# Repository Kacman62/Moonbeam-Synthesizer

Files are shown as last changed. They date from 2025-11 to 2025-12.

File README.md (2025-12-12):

# MoonBeam Synthesizer
A standalone DAWLESS synthesizer based on a Raspberry Pi Pico. Includes a custom circuit board and codebase with the Mozzi Audio Library

Promo Image for the Moonbeam Synth

# Features

- 25 multiplexed piano style keys
- Support for up to 5 notes at the same time
- 3 Analog sliders for volume pitch and vibrato
- OLED display and 2 rotary encoders with a custom code base
- Sound synthesis using the Mozzi audio library
- 4 different wave forms
- Custom ADSR editing
- Oscilloscope style waveform viewer
- Toggleable speaker and headphone out
- Audio effects and filters
- Preset sound fforms

# Initial Idea
After reading the guide from Hack club and others online to make a MIDI keyboard, it seemed like a great idea. After more research though I wanted a standalone synthesizer that does not need a computer and couldn't find many examples online. This seemed like it would be easy enough so I decided to do it myself

# Schematic and Board
The whole project is built around a raspberry pi pico 1 (a pico 2 should work too but untested). A 5x5 multiplexed array of key cap switches serve as the main input. 
On the Audio side, a PCM5100 I2S DAC is channeled into a LM4810 and LM4861 audio amplifiers, that go to a speaker and headphone jack.

Image showing routing of PCB

The PCB was a lot more challenging, just due to the sheer size of it. It ends up being about 350mm x 90mm. But the routing wasn't too hard and I like the look of how it turned out

# Case Design
There is an included case. Currently I have not received the board so I can not confirm if it works perfectly, but I designed it around the 3D cad of the board so it should work fine. 
Only 1 of each file needs to be printed and it is assembled using M4 hardware

Image showing CAD of the case

# Software
I initially dreaded the software but it ended up being very fun after the initial hurdles. The code is split into 2 cores, 1 for audio and 1 for the digital UI. It should work with the final assembly, all the digital has been tested, but the audio is using I2S which I can't test currently. I did use it a little bit with PWM audio and that worked fine. The waveform viewer also does show an audio signal so Im pretty confident that it will work

# UI
You navigate the UI with both rotary encoders. Double clicking either brings you into the main menu. Rotate either to select an app.
* Settings (Wrench): View current notes on each audio voice and the values of the slide potentiometers
* ADSR Editor (Envelope): Use one dial to change the level of the ADSR and the other to change the time. Changing the level of the decay, sustain and release will change the other two with it. this is intended to avoid weird audio clipping
* Wave Viewer (Wave): View the current outputted wave form. Automatically adjusts the zoom if multiple voices are playing
* Wave Changer (Square Wave): Choose from either a sin, triangle, saw, or square wave

Image showing the settings UI

# Art
All pixel art was created by me using Aseprite. The PK Industries and the Moonbeam synth logo are unregistered trademarks, not real companies and products, and have no legal binding on anything. I am not a lawyer, and this joke has gone on too long.

Image showing the pixel art for the project

# Disclaimers
If you want to know more about the design and build process check out the journal

This project is sponsored by and made in collaboration with Hack Club, go check them out

Consider this project untested. I have put my full effort into this project and fully believe that it will work, but I have not received boards yet and thus do not know if this will work first try

# Hack Club Stuff

Estimate Total Hours: 48

My Final Total: 60.31

Your Final Total: 96.73

https://blueprint.hackclub.com/projects/928 

# Update 11/11

Huge thanks to Hack Club and the Blueprint program for assisting in this project. I have now received funding for the project and will be ordering parts. Expect future updates at the start of December

# Update 11/25

Boards have been received. Still waiting on LCSC order. Small errors have been found in the board and have been fixed in the PCB files

# Update 12/1

Boards have been assembled and multiple errors have been found. The files will still be up, but assume they do not work.
Nothing shorts together, but both the button matrix is broken, as well as the I2S DAC and amplifier not working.

# Update 12/3

After reflowing the baord, the issue has been fixed. Two of the data lines into the DAC were shorted and after fixing that, it makes sound. The code still has some issues, but they are being fixed rapidly and the current board is almost done.

# Update 12/4 

This project is now shipped. I had a lot of fun working on this, and will continue to update the software, but for now the project is in a working state so expect less updates.

# Update 12/12 

Version 1 of software is now released. This features upgrades to all parts of the code base. Numerous bug fixes, rewritten audio workflow. Support for filters, effects, and presets. Improved menus and clarity. 

# Known issues

Code: 

In settings, the note played is incorrect (going to wait for boards to arrive so I can assign keys different notes) Fixed 12/12/25

Button scanning matrix is incorrect, every button plays the same 5 notes FIXED 12/3/25

In Wave changer, the picture of the sawtooth wave is reversed from what is seen in the wave viewer

In Wave Viewer, the wave slides around randomly. (The wave is still representative of what the audio out looks like, it's just hard to focus on it)

Distortion effect is unstable and clips audio most of the time. Still able to be used in code, but not recomended

Board:

Slide pot pin spacing 2.00mm instead of 2.54mm FIXED 11/25/25

Resistor footprint 7.62mm instead of 12.04mm FIXED 11/25/25

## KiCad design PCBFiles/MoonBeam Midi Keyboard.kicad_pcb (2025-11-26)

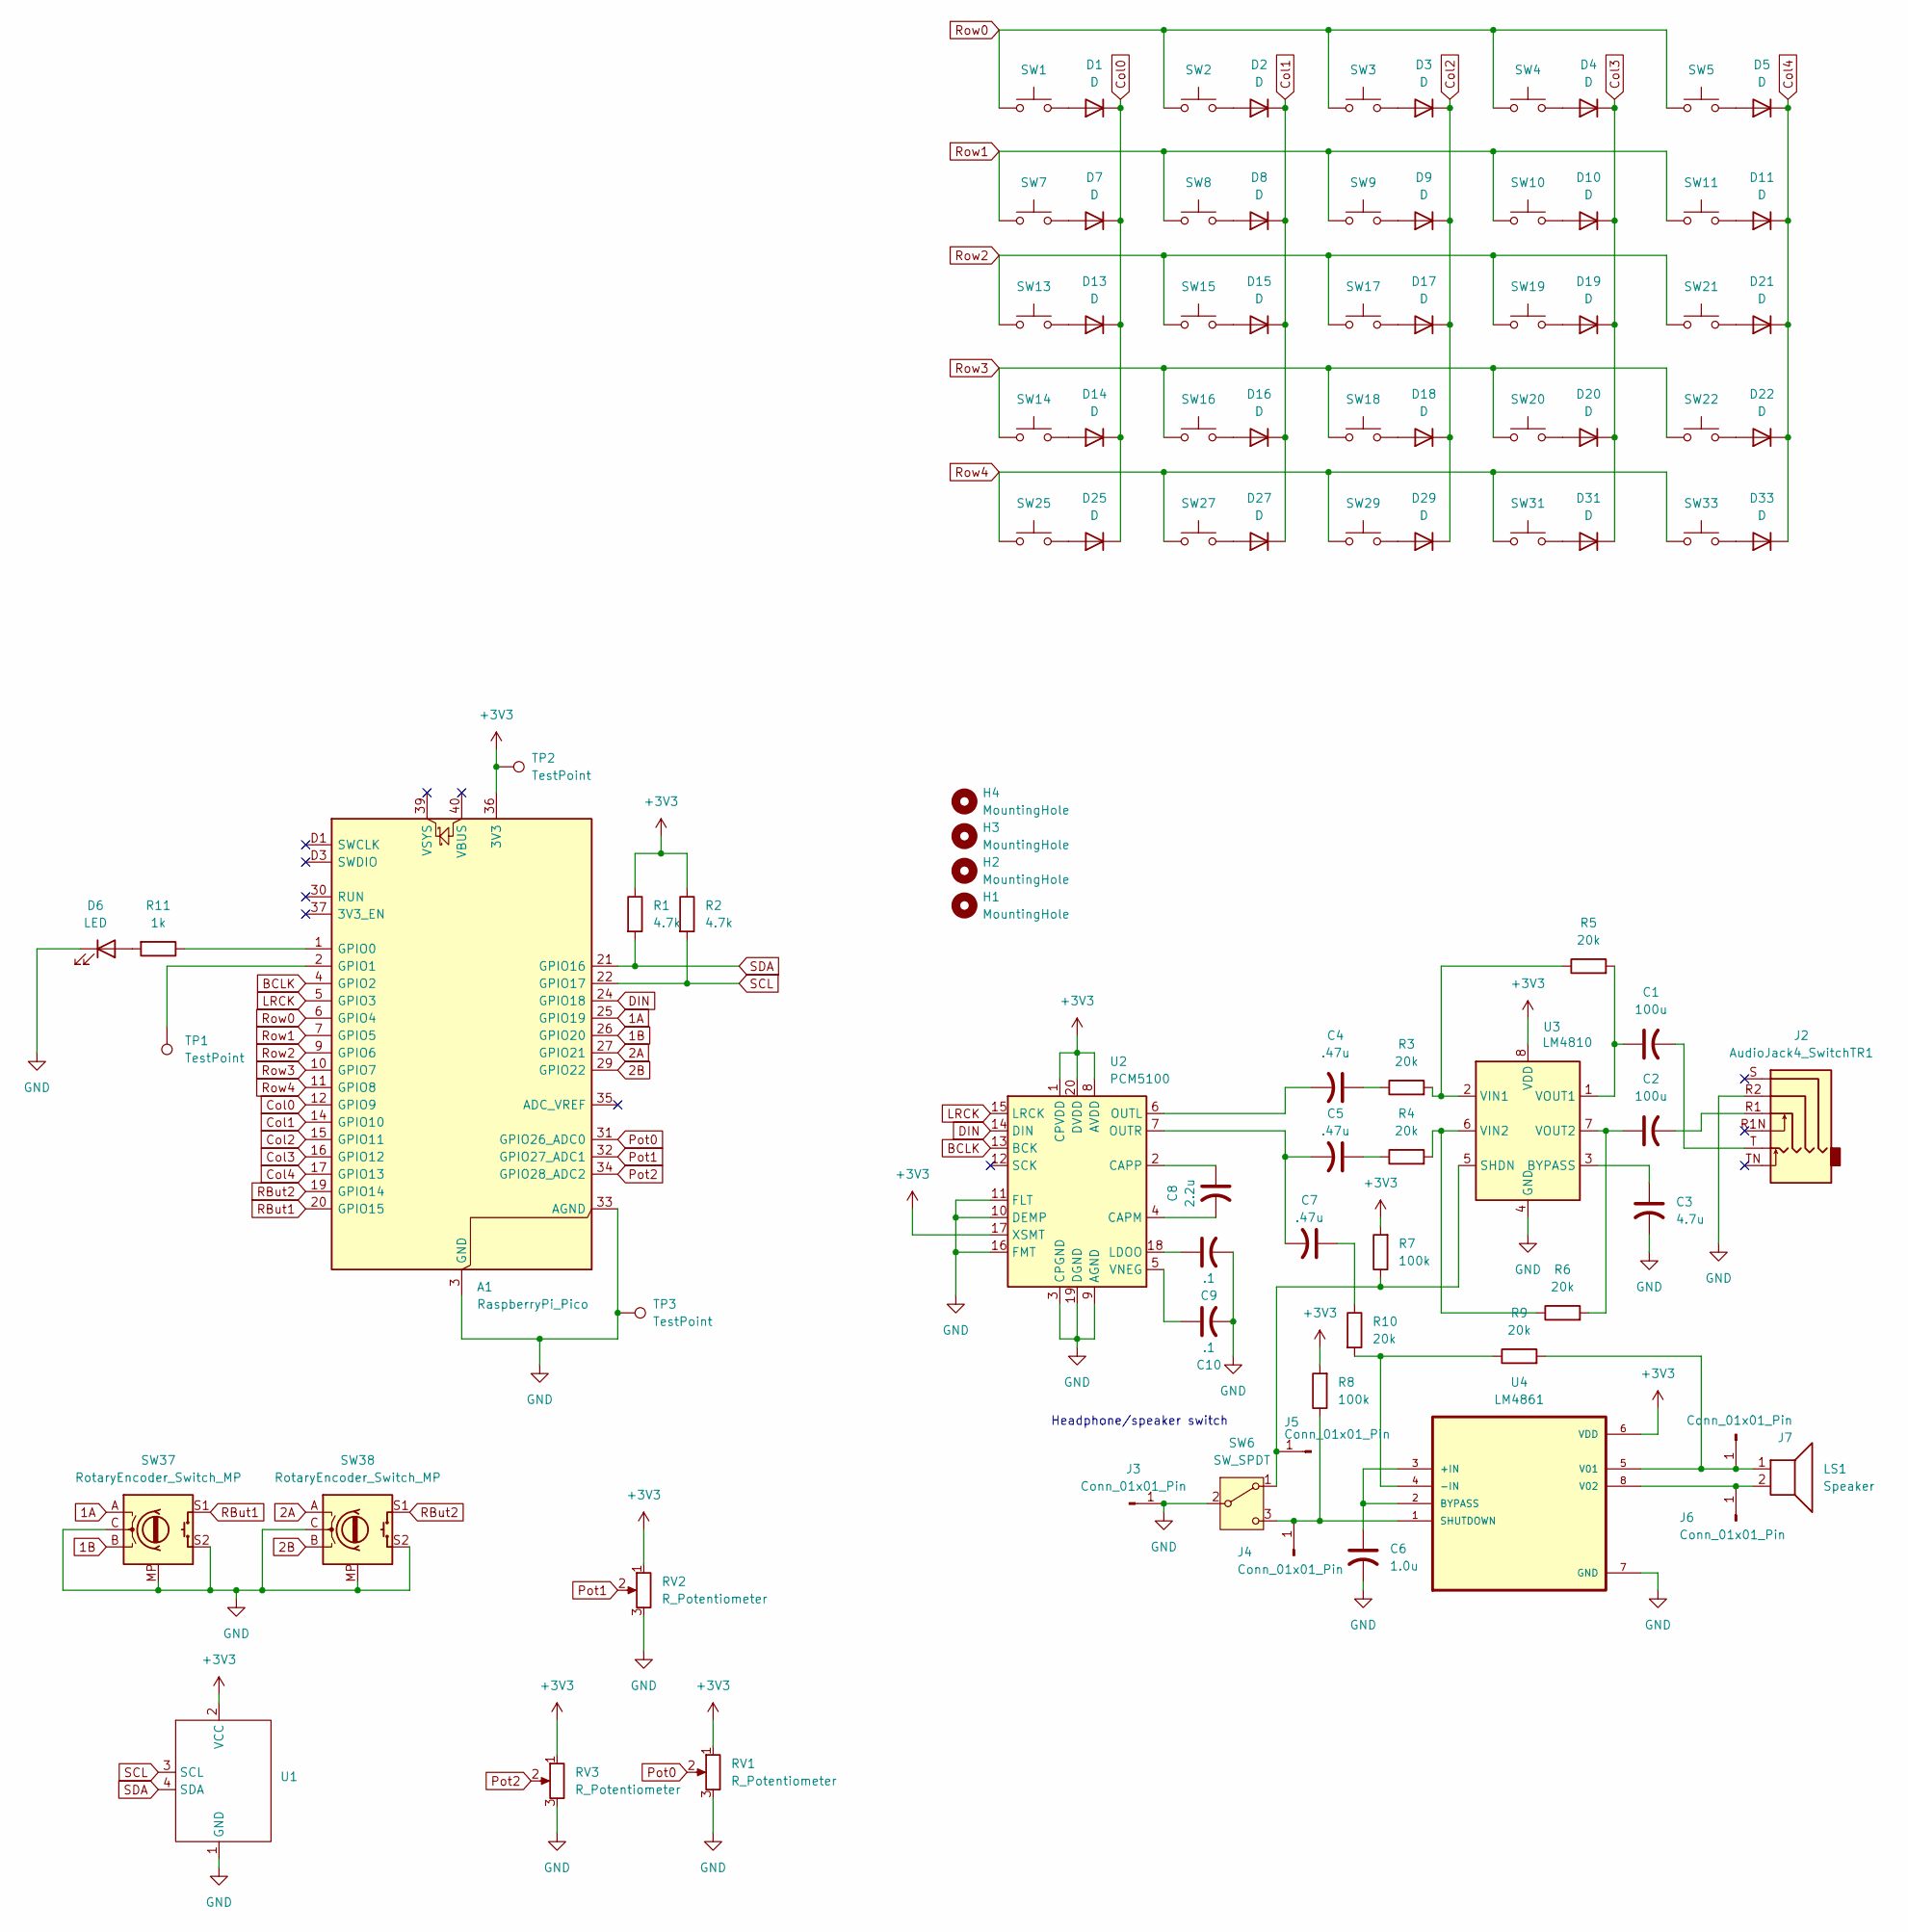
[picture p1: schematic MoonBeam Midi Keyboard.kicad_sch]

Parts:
A1: RaspberryPi_Pico; RaspberryPi_Pico_Common_THT
C1, C2: 100u; CP_Radial_D5.0mm_P2.50mm
C3: 4.7u; CP_Radial_D5.0mm_P2.50mm
C4, C5, C7: .47u; CP_Radial_D5.0mm_P2.50mm
C6: 1.0u; CP_Radial_D5.0mm_P2.50mm
C8: 2.2u; CP_Radial_D5.0mm_P2.50mm
C9, C10: .1; CP_Radial_D5.0mm_P2.50mm
D1, D2, D3, D4, D5, D7, D8, D9, D10, D11, D13, D14, D15, D16, D17, D18, D19, D20, D21, D22, D25, D27, D29, D31, D33: D; D_DO-35_SOD27_P7.62mm_Horizontal
D6: LED; LED_D3.0mm
H1, H2, H3: MountingHole; MountingHole_4.3mm_M4
H4: MountingHole; MountingHole_4.3mm_M4_DIN965
J2: AudioJack4_SwitchTR1; Jack_3.5mm_PJ31060-I_Horizontal
J3, J4, J5, J6, J7: Conn_01x01_Pin; TestPoint_Pad_4.0x4.0mm
LS1: Speaker
R1, R2: 4.7k; R_Axial_DIN0207_L6.3mm_D2.5mm_P10.16mm_Horizontal
R3, R4, R5, R6, R9, R10: 20k; R_Axial_DIN0207_L6.3mm_D2.5mm_P10.16mm_Horizontal
R7, R8: 100k; R_Axial_DIN0207_L6.3mm_D2.5mm_P10.16mm_Horizontal
R11: 1k; R_Axial_DIN0207_L6.3mm_D2.5mm_P10.16mm_Horizontal
RV1, RV2, RV3: R_Potentiometer; Slide Pot
SW1, SW2, SW3, SW4, SW5, SW7, SW8, SW9, SW10, SW11, SW13, SW14, SW15, SW16, SW17, SW18, SW19, SW20, SW21, SW22, SW25, SW27, SW29, SW31, SW33: SW_Omron_B3FS; SW_Cherry_MX_1.00u_PCB
SW6: SW_SPDT
SW37, SW38: RotaryEncoder_Switch_MP; RotaryEncoder_Alps_EC11E-Switch_Vertical_H20mm_MountingHoles
TP1, TP2, TP3: TestPoint; TestPoint_Pad_4.0x4.0mm
U1: 0.96 OLED I2C
U2: PCM5100; TSSOP-20_4.4x6.5mm_P0.65mm
U3: LM4810; TSSOP-8_3x3mm_P0.65mm
U4: LM4861; SOIC127P600X175-8N

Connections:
1A: A1.25 (GPIO19), SW37.A
1B: A1.26 (GPIO20), SW37.B
2A: A1.27 (GPIO21), SW38.A
2B: A1.29 (GPIO22), SW38.B
+3V3: A1.36 (3V3), R1.1, R2.1, R7.2, R8.2, RV1.1, RV2.1, RV3.1, TP2.1, U1.2 (VCC), U2.1 (CPVDD), U2.8 (AVDD), U2.17 (XSMT), U2.20 (DVDD), U3.8 (VDD), U4.6 (VDD); also elsewhere on the board
BCLK: A1.4 (GPIO2), U2.13 (BCK)
Col0: A1.12 (GPIO9), D1.1 (K), D7.1 (K), D13.1 (K), D14.1 (K), D25.1 (K)
Col1: A1.14 (GPIO10), D2.1 (K), D8.1 (K), D15.1 (K), D16.1 (K), D27.1 (K)
Col2: A1.15 (GPIO11), D3.1 (K), D9.1 (K), D17.1 (K), D18.1 (K), D29.1 (K)
Col3: A1.16 (GPIO12), D4.1 (K), D10.1 (K), D19.1 (K), D20.1 (K), D31.1 (K)
Col4: A1.17 (GPIO13), D5.1 (K), D11.1 (K), D21.1 (K), D22.1 (K), D33.1 (K)
DIN: A1.24 (GPIO18), U2.14 (DIN)
GND: A1.3 (GND), A1.8 (GND), A1.13 (GND), A1.18 (GND), A1.23 (GND), A1.28 (GND), A1.33 (AGND), A1.38 (GND), A1.D2 (GND), C3.2, C6.2, C9.2, C10.2, D6.1 (K), J2.R2, J3.1, RV1.3, RV2.3, RV3.3, SW6.2 (B), SW37.C, SW37.MP, SW37.S2, SW38.C, SW38.MP, SW38.S2, TP3.1, U1.1 (GND), U2.3 (CPGND), U2.9 (AGND), U2.10 (DEMP), U2.11 (FLT), U2.16 (FMT), U2.19 (DGND), U3.4 (GND), U4.7 (GND); also elsewhere on the board
LRCK: A1.5 (GPIO3), U2.15 (LRCK)
unnamed: A1.1 (GPIO0), R11.1
unnamed 15: A1.2 (GPIO1), TP1.1; also elsewhere on the board
unnamed: C1.2, J2.T
unnamed: C2.2, J2.R1
unnamed: C4.1, R3.1
unnamed: C5.1, R4.1
unnamed: C7.1, R10.1
unnamed: D1.2 (A), SW1.2
unnamed: D2.2 (A), SW2.2
unnamed: D3.2 (A), SW3.2
unnamed: D4.2 (A), SW4.2
unnamed: D5.2 (A), SW5.2
unnamed: D6.2 (A), R11.2
unnamed: D7.2 (A), SW7.2
unnamed: D8.2 (A), SW8.2
unnamed: D9.2 (A), SW9.2
unnamed: D10.2 (A), SW10.2
unnamed: D11.2 (A), SW11.2
unnamed: D13.2 (A), SW13.2
unnamed: D14.2 (A), SW14.2
unnamed: D15.2 (A), SW15.2
unnamed: D16.2 (A), SW16.2
unnamed: D17.2 (A), SW17.2
unnamed: D18.2 (A), SW18.2
unnamed: D19.2 (A), SW19.2
unnamed: D20.2 (A), SW20.2
unnamed: D21.2 (A), SW21.2
unnamed: D22.2 (A), SW22.2
unnamed: D25.2 (A), SW25.2
unnamed: D27.2 (A), SW27.2
unnamed: D29.2 (A), SW29.2
unnamed: D31.2 (A), SW31.2
unnamed: D33.2 (A), SW33.2
unnamed: J4.1, R8.1, SW6.3 (C), U4.1 (SHUTDOWN)
unnamed: J5.1, R7.1, SW6.1 (A), U3.5 (SHDN)
unnamed: J6.1, LS1.2, U4.8 (V02)
unnamed: J7.1, LS1.1, R9.2, U4.5 (V01)
unnamed: C8.2, U2.4 (CAPM)
unnamed: C8.1, U2.2 (CAPP)
unnamed: C9.1, U2.18 (LDOO)
unnamed: C4.2, U2.6 (OUTL)
unnamed: C5.2, C7.2, U2.7 (OUTR)
unnamed: C10.1, U2.5 (VNEG)
unnamed: C3.1, U3.3 (BYPASS)
unnamed: R3.2, R5.1, U3.2 (VIN1)
unnamed: R4.2, R6.1, U3.6 (VIN2)
unnamed: C1.1, R5.2, U3.1 (VOUT1)
unnamed: C2.1, R6.2, U3.7 (VOUT2)
unnamed: C6.1, U4.2 (BYPASS), U4.3 (+IN)
unnamed: R9.1, R10.2, U4.4 (-IN)
Pot0: A1.31 (GPIO26_ADC0), RV1.2
Pot1: A1.32 (GPIO27_ADC1), RV2.2
Pot2: A1.34 (GPIO28_ADC2), RV3.2
RBut1: A1.20 (GPIO15), SW37.S1
RBut2: A1.19 (GPIO14), SW38.S1
Row0: A1.6 (GPIO4), SW1.1, SW2.1, SW3.1, SW4.1, SW5.1
Row1: A1.7 (GPIO5), SW7.1, SW8.1, SW9.1, SW10.1, SW11.1
Row2: A1.9 (GPIO6), SW13.1, SW15.1, SW17.1, SW19.1, SW21.1
Row3: A1.10 (GPIO7), SW14.1, SW16.1, SW18.1, SW20.1, SW22.1
Row4: A1.11 (GPIO8), SW25.1, SW27.1, SW29.1, SW31.1, SW33.1
SCL: A1.22 (GPIO17), R2.2, U1.3 (SCL)
SDA: A1.21 (GPIO16), R1.2, U1.4 (SDA)

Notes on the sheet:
Headphone/speaker switch

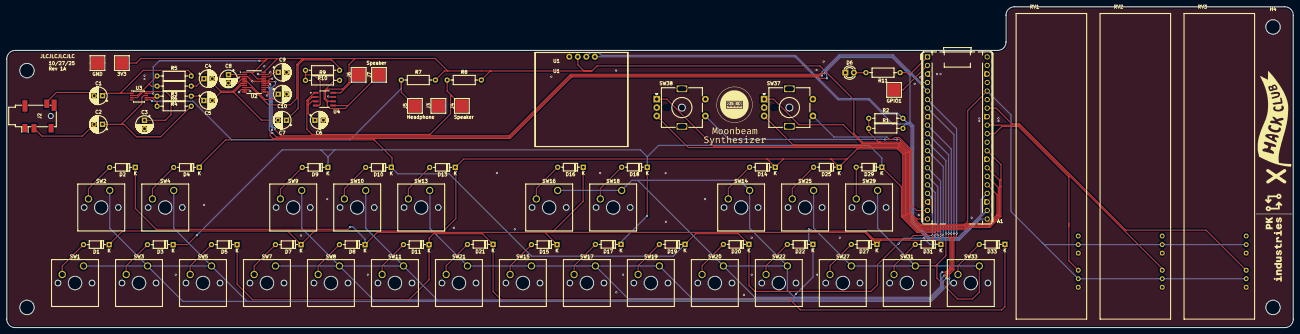
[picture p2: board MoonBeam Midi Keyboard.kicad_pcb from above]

Board: 2 copper layers, 383.0 x 95.5 mm, 95 parts (0 on the bottom side), 76 nets.

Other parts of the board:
3V3: Conn_01x01_Pin; TestPoint_Pad_4.0x4.0mm
GND: Conn_01x01_Pin; TestPoint_Pad_4.0x4.0mm
GPIO1: Conn_01x01_Pin; TestPoint_Pad_4.0x4.0mm

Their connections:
+3V3: 3V3.1; also elsewhere on the board
GND: GND.1; also elsewhere on the board
unnamed 15: GPIO1.1; also elsewhere on the board

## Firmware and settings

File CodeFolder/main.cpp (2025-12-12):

#include "Wire.h"
#include "pico/multicore.h"
#include "core_shared.h"

#include "MozziConfigValues.h" // for named option values
#define MOZZI_AUDIO_MODE MOZZI_OUTPUT_I2S_DAC
#define MOZZI_AUDIO_CHANNELS MOZZI_STEREO
#define MOZZI_AUDIO_BITS 16
#define MOZZI_AUDIO_RATE 32768
#define MOZZI_I2S_PIN_BCK 2
#define MOZZI_I2S_PIN_WS (MOZZI_I2S_PIN_BCK + 1) // HAS TO BE NEXT TO pBCLK, i.e. default is 21
#define MOZZI_I2S_PIN_DATA 18
#define MOZZI_CONTROL_RATE 128 // mozzi rate for updateControl()
#include "Mozzi.h"             // *after* all configuration options, include the main Mozzi headers

#include "main.h"
#include "settings.h"
#include "filters.h"

MultiResonantFilter<uint16_t> mf;

#define VOL_POT A0
#define PITCH_POT A1
#define VIB_POT A2

volatile float masterVol = 1.0f;
volatile float pitchOffset = 1.0f;
volatile float vibDepth = 1.0f;

float GAIN = 20.0f;

#define NUM_COLS 5
#define NUM_ROWS 5

Oscil<SIN2048_NUM_CELLS, AUDIO_RATE> osc[NUM_VOICES] = {
    Oscil<SIN2048_NUM_CELLS, AUDIO_RATE>(SIN2048_DATA),
    Oscil<SIN2048_NUM_CELLS, AUDIO_RATE>(SIN2048_DATA),
    Oscil<SIN2048_NUM_CELLS, AUDIO_RATE>(SIN2048_DATA),
    Oscil<SIN2048_NUM_CELLS, AUDIO_RATE>(SIN2048_DATA),
    Oscil<SIN2048_NUM_CELLS, AUDIO_RATE>(SIN2048_DATA)};

ADSR<CONTROL_RATE, AUDIO_RATE> env[NUM_VOICES] = {
    ADSR<MOZZI_CONTROL_RATE, MOZZI_AUDIO_RATE>(), // if audio is slow chane mAudioRate to mControlRate
    ADSR<MOZZI_CONTROL_RATE, MOZZI_AUDIO_RATE>(),
    ADSR<MOZZI_CONTROL_RATE, MOZZI_AUDIO_RATE>(),
    ADSR<MOZZI_CONTROL_RATE, MOZZI_AUDIO_RATE>(),
    ADSR<MOZZI_CONTROL_RATE, MOZZI_AUDIO_RATE>()};

volatile SharedADSR adsrSettings;

volatile bool ADSR_FLAG = false;
volatile bool OSC_FLAG = false;
volatile bool LFO_FLAG = false;

volatile float LFO_FREQ = 5.0f;

volatile OSCState wave = SIN;

extern const unsigned char sinWave[];
extern const unsigned char triWave[];
extern const unsigned char sawWave[];
extern const unsigned char squareWave[];
extern const unsigned char *waveTable[];
extern const unsigned char *waveTable[];

extern volatile float userOctaveOffset;

Oscil<SIN2048_NUM_CELLS, MOZZI_CONTROL_RATE> lfo(SIN2048_DATA); // LFO for vibrato
Oscil<SIN2048_NUM_CELLS, AUDIO_RATE> subOsc(SQUARE_NO_ALIAS_2048_DATA);

int ButtonMatrixRow[NUM_ROWS] = {4, 5, 6, 7, 8};
int ButtonMatrixCol[NUM_COLS] = {9, 10, 11, 12, 13};

float notePlayArray[NUM_VOICES];
int notePlayButtons[NUM_VOICES];
bool releaseFlag[NUM_VOICES];

float noteFreqs[NUM_ROWS * NUM_COLS] = {
    /*261.63, 277.18, 293.66, 311.13, 329.63,
    349.23, 369.99, 392.00, 415.30, 440.00,
    466.16, 493.88, 523.25, 554.37, 587.33,
    622.25, 659.25, 698.46, 739.99, 783.99,
    830.61, 880.00, 932.33, 987.77, 1046.5*/
    261.63, 277.18, 293.66, 311.13, 329.63,
    349.23, 392.00, 369.99, 415.30, 440.00,
    466.16, 523.25, 587.33, 659.25, 493.88,
    739.99, 554.37, 622.25, 698.46, 783.99,
    830.61, 880.00, 932.33, 987.77, 1046.5}; // C4-C6
                                             // Nomalized to my weird button layout

void setup()
{

  pinMode(0, OUTPUT);
  digitalWrite(0, HIGH);
  delay(500);
  digitalWrite(0, LOW);
  delay(200);

  updateADSR();
  updateOSC();
  updateLFO();

  lfo.setFreq(LFO_FREQ);

  digitalWrite(0, HIGH);
  delay(500);
  digitalWrite(0, LOW);
  delay(20);
  digitalWrite(0, HIGH);
  delay(500);
  digitalWrite(0, LOW);
  delay(200);

  for (int r = 0; r < NUM_ROWS; r++)
  {
    pinMode(ButtonMatrixRow[r], OUTPUT);
    digitalWrite(ButtonMatrixRow[r], LOW);
  }

  for (int c = 0; c < NUM_COLS; c++)
  {
    pinMode(ButtonMatrixCol[c], INPUT_PULLDOWN);
  }

  for (int i = 0; i < NUM_VOICES; i++)
  {
    notePlayArray[i] = -1.0f;
    notePlayButtons[i] = -1;
    releaseFlag[i] = false;
  }

  analogReadResolution(12); // 0–4095

  startMozzi();
}

const int WAVEFORM_SAMPLES = 128;
volatile int16_t waveformBuffer[WAVEFORM_SAMPLES];
volatile int waveformIndex = 0;

void writeSample(int16_t sample)
{
  waveformBuffer[waveformIndex] = sample;
  waveformIndex = (waveformIndex + 1) % WAVEFORM_SAMPLES;
}

float lpfState = 0;

inline int16_t lowpass(int16_t input)
{
  lpfState += 0.1f * (input - lpfState); // 0.05–0.3 = cutoff
  return (int16_t)lpfState;
}

AudioOutput updateAudio()
{
  int32_t mix = 0;

  // must loop through every voice, because no voice stealing or auto adjust voice positions
  for (int i = 0; i < NUM_VOICES; i++)
  {
    if (notePlayButtons[i] < 0 && releaseFlag[i] == false)
    {
      continue;
    }
    auto envelopeLevel = env[i].next();

    if (envelopeLevel == 0)
    {
      releaseFlag[i] = false;
      continue;
    }

    int32_t oscSample = osc[i].next();
    mix += (int)((oscSample * envelopeLevel) / 255.0f);
  }

  mix = applyEffects(mix);

  mix = (mix * masterVol);

  if (mix > 32767)
    mix = 32767;
  if (mix < -32768)
    mix = -32768;

  writeSample((int16_t)mix);

  return StereoOutput::from16Bit((int16_t)mix, (int16_t)mix);
}

void loop()
{
  audioHook();
}

void updateControl()
{
  masterVol = analogRead(VOL_POT) / 4095.0;

  float rawSemis = (analogRead(PITCH_POT) / 4095.0f) * 24.0f + (12.0f * userOctaveOffset);
  pitchOffset = roundf(rawSemis);
  float pitchShift = powf(2.0f, pitchOffset / 12.0f);

  vibDepth = analogRead(VIB_POT) / 4095.0f;

  if (ADSR_FLAG)
  {
    updateADSR();
  }

  if (OSC_FLAG)
  {
    updateOSC();
  }

  if (LFO_FLAG)
  {
    updateLFO();
  }

  scanMatrix();

  for (int i = 0; i < NUM_VOICES; i++)
  {
    if (notePlayArray[i] < 0)
      continue;

    env[i].update();

    float baseFreq = notePlayArray[i];

    float lfoValue = lfo.next() / 128.0f;

    float reducedVibDepth = vibDepth / 4;

    float vibratoFactor = powf(2.0f, (lfoValue * reducedVibDepth) / 12.0f);

    // Apply pitch shift and vibrato
    float finalFreq = baseFreq * pitchShift * vibratoFactor;

    osc[i].setFreq(finalFreq);
  }

  float cutoff = 180.0f;
  float resonance = 200.0f;

  mf.setCutoffFreqAndResonance(cutoff, resonance);
}

void scanMatrix()
{

  for (int r = 0; r < NUM_ROWS; r++)
  {
    pinMode(ButtonMatrixRow[r], OUTPUT);
    digitalWrite(ButtonMatrixRow[r], HIGH);

    for (int c = 0; c < NUM_COLS; c++)
    {
      int currentButton = r * NUM_COLS + c;
      int buttonPlaying = isButtonPlaying(currentButton);

      auto state = digitalRead(ButtonMatrixCol[c]);

      int freeVoice = getFreeVoice();

      if (state == HIGH && freeVoice != -1 && buttonPlaying == -1)
      {

        notePlayArray[freeVoice] = noteFreqs[currentButton];
        notePlayButtons[freeVoice] = currentButton;
        env[freeVoice].noteOn();

        osc[freeVoice].setFreq(notePlayArray[freeVoice]);
      }

      if (state == LOW && buttonPlaying > -1)
      {
        notePlayArray[buttonPlaying] = -1.0f;
        notePlayButtons[buttonPlaying] = -1;
        env[buttonPlaying].noteOff();
        releaseFlag[buttonPlaying] = true;
      }

      pinMode(ButtonMatrixCol[c], INPUT_PULLDOWN);
    }
    digitalWrite(ButtonMatrixRow[r], LOW);
  }
}

int getFreeVoice()
{
  for (int i = 0; i < NUM_VOICES; i++)
  {
    if (notePlayArray[i] < 0)
    {
      return i;
    }
  }
  return -1;
}

int isButtonPlaying(int button)
{
  for (int i = 0; i < NUM_VOICES; i++)
  {
    if (notePlayButtons[i] == button)
    {
      return i;
    }
  }
  return -1;
}

void updateADSR()
{
  for (int i = 0; i < NUM_VOICES; i++)
  {
    env[i].setLevels(adsrSettings.attack, adsrSettings.decay, adsrSettings.sustain, adsrSettings.release);
    env[i].setTimes(adsrSettings.attackTime, adsrSettings.decayTime, adsrSettings.sustainTime, adsrSettings.releaseTime);
  }
  ADSR_FLAG = false;
}

void updateOSC()
{
  for (int i = 0; i < NUM_VOICES; i++)
  {

    switch (wave)
    {

    case SIN:
      osc[i].setTable(SIN2048_DATA);
      setGain(20);
      break;

    case TRIANGLE:
      osc[i].setTable(TRIANGLE2048_DATA);
      setGain(20);
      break;

    case SAW:
      osc[i].setTable(SAW2048_DATA);
      setGain(20);
      break;

    case SQUARE:
      osc[i].setTable(SQUARE_NO_ALIAS_2048_DATA);
      setGain(20);
      break;
    }
  }
  OSC_FLAG = false;
}

void updateLFO()
{

  lfo.setFreq(LFO_FREQ);
  LFO_FLAG = false;
}

void setGain(int amount)
{
  GAIN = amount;
}

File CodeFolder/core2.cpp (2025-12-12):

// Lets find the memory leak

#include <Adafruit_SSD1306.h>
#include <Adafruit_gfx.h>
#include <Fonts/FreeMono12pt7b.h>
#include <EEncoder.h>
#include <Button2.h>
#include <cmath>

#include "core_shared.h"
#include "images.h"
#include "settings.h"
#include "presets.h"

#define SDA 16
#define SCL 17

#define SCREEN_WIDTH 128 // OLED display width, in pixels
#define SCREEN_HEIGHT 64 // OLED display height, in pixels

#define OLED_RESET -1
#define SCREEN_ADDRESS 0x3C

Adafruit_SSD1306 display(SCREEN_WIDTH, SCREEN_HEIGHT, &Wire, OLED_RESET);

int RotaryButton1 = 15;
EEncoder encoder1(19, 20);
Button2 button1(RotaryButton1);

int RotaryButton2 = 14;
EEncoder encoder2(21, 22);
Button2 button2(RotaryButton2);

long lastPos1;
long lastPos2;

void onButtonClick1(Button2 &btn);
void onButtonClick2(Button2 &btn);
void onButtonDoubleClick1(Button2 &btn);
void onButtonDoubleClick2(Button2 &btn);
void animationIntro();
void openCloseAnimation(bool open, const unsigned char *bitMapOut);
void updateScreen();

void showDiagnostics();
void showMain();
void showOscSettings();
void showADSR();
void showWaveForm();
void showSettings();
void showPreset();

void onEncoderRotate(EEncoder &enc);

extern const unsigned char *waveTable[];

extern volatile float notePlayArray[];

enum menuState
{
    MAIN_MENU,     // Sekect other menus here
    DIAGNOSTICS,   // Show current pot values and other settings (maybe also what note is playing)
    ADSR_SETTINGS, // Tweak the envolope show a waveform of what it looks like
    WAVEFORM,      // Show waveform of current played note
    OSC_SETTINGS,  // Change osc shape
    SETTINGS,      // Change Settings
    PRESETS,       // preset ADSR etc
    LOOPER,        // looper or sequencer probably do this last
    CHORDS         // play chords with single button and change major minor etc.
};

menuState Menu = MAIN_MENU;

extern volatile SharedADSR adsrSettings;

int mainMenuItem = 0;

int oscSettingSelected = 0;
int oscSettingMax = 4;

int adsrSettingSelected = 0;
int adsrSettingMax = 4;

int settingMenuSelected = 0;
int presetMenuSelected = 0;

volatile float userOctaveOffset = -1.0f;

void setup1()
{

    Serial.begin(115200);

    // Blink LED so i know its working (ONLY FOR DEBUGGING)
    pinMode(25, OUTPUT);
    digitalWrite(25, HIGH);
    delay(500);
    digitalWrite(25, LOW);

    Wire.setSDA(SDA);
    Wire.setSCL(SCL);
    Wire.begin();

    delay(50);

    Serial.println("Init OLED...");
    display.begin(SSD1306_SWITCHCAPVCC, SCREEN_ADDRESS);
    display.display();
    Serial.println("OLED init done");

    display.clearDisplay();

    display.drawBitmap(0, 0, PKI_Logo_BW, 127, 64, 1);
    display.display();
    display.setFont(NULL);

    button1.begin(RotaryButton1, INPUT_PULLUP, true);
    button1.setClickHandler(onButtonClick1);
    button1.setDoubleClickHandler(onButtonDoubleClick1);

    button2.begin(RotaryButton2, INPUT_PULLUP, true);
    button2.setClickHandler(onButtonClick2);
    button2.setDoubleClickHandler(onButtonDoubleClick2);

    encoder1.setEncoderHandler(onEncoderRotate);
    encoder2.setEncoderHandler(onEncoderRotate);

    encoder1.setAcceleration(false);
    // encoder1.setAccelerationRate(5);
    encoder2.setAcceleration(false);
    // encoder2.setAccelerationRate(5);

    delay(1000);

    display.clearDisplay();

    display.drawBitmap(0, 0, MoonBeamSynth, 127, 64, 1);
    display.display();

    delay(1500);

    display.clearDisplay();
}

void onButtonClick1(Button2 &btn)
{

    if (Menu == MAIN_MENU)
    {
        Menu = static_cast<menuState>(mainMenuItem + 1); //+1 because 0th item is main menu

        if (mainMenuItem == 1)
        {
            adsrSettingSelected--; // maybe shoulda debounced it or smth
            encoder1.setAcceleration(true);
            encoder1.setAccelerationRate(5);
        }
    }

    if (Menu == OSC_SETTINGS)
    {
        wave = static_cast<OSCState>(oscSettingSelected);
        OSC_FLAG = true;
    }

    if (Menu == ADSR_SETTINGS)
    {

        ADSR_FLAG = true;
        adsrSettingSelected++;

        // Wrap around
        if (adsrSettingSelected < 0)
            adsrSettingSelected = adsrSettingMax - 1;
        if (adsrSettingSelected >= adsrSettingMax)
            adsrSettingSelected = 0;

        Serial.print("adsr Setting Item: ");
        Serial.println(adsrSettingSelected);
    }

    if (Menu == SETTINGS && inItem == -1)
    {
        inItem = settingMenuSelected;
    }

    if (Menu == SETTINGS && inItem > -1)
    {
        settings[settingMenuSelected].effectActive = !settings[settingMenuSelected].effectActive;
    }

    if (Menu == PRESETS)
    {
        applyPreset(presetMenuSelected);
    }
}

void onButtonClick2(Button2 &btn)
{

    if (Menu == MAIN_MENU)
    {
        Menu = static_cast<menuState>(static_cast<int>(Menu) + mainMenuItem + 1);

        if (mainMenuItem == 1)
        {
            adsrSettingSelected--;
            encoder1.setAcceleration(true);
            encoder1.setAccelerationRate(5);
        }
    }

    if (Menu == OSC_SETTINGS)
    {
        OSC_FLAG = true;
        wave = static_cast<OSCState>(static_cast<int>(wave) + oscSettingSelected);
    }

    if (Menu == ADSR_SETTINGS)
    {
        ADSR_FLAG = true;
        adsrSettingSelected++;

        // Wrap around
        if (adsrSettingSelected < 0)
            adsrSettingSelected = adsrSettingMax - 1;
        if (adsrSettingSelected >= adsrSettingMax)
            adsrSettingSelected = 0;

        Serial.print("adsr Setting Item: ");
        Serial.println(adsrSettingSelected);
    }

    if (Menu == SETTINGS && inItem == -1)
    {
        inItem = settingMenuSelected;
    }

    if (Menu == SETTINGS && inItem > -1)
    {
        settings[settingMenuSelected].effectActive = !settings[settingMenuSelected].effectActive;
    }

    if (Menu == PRESETS)
    {
        applyPreset(presetMenuSelected);
    }
}

void onButtonDoubleClick1(Button2 &btn)
{

    if (Menu == ADSR_SETTINGS)
    {
        ADSR_FLAG = true;
        encoder1.setAcceleration(false);
        encoder2.setAcceleration(false);
    }

    if (Menu == SETTINGS && inItem > -1)
    {
        inItem = -1;
        return;
    }

    if (Menu == SETTINGS)
    {
        applySettings();
    }

    Menu = MAIN_MENU;
}

void onButtonDoubleClick2(Button2 &btn)
{

    if (Menu == ADSR_SETTINGS)
    {
        ADSR_FLAG = true;
        encoder1.setAcceleration(false);
        encoder2.setAcceleration(false);
    }

    if (Menu == SETTINGS && inItem > -1)
    {
        inItem = -1;
        return;
    }

    Menu = MAIN_MENU;
}

long lastRefresh = micros();

void loop1()
{

    if (micros() - lastRefresh > 16666)
    { // yeah this fixes issue below. theres 2 hours ill never get back

        updateScreen(); // i think calling this to much is messing with the encoders
        lastRefresh = micros();
    }

    encoder1.update();
    encoder2.update();

    button1.loop();
    button2.loop();
}
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

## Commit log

2025-11-26 added updated PCB files
    [MoonBeam Midi Keyboard.kicad_pcb, MoonBeam Midi Keyboard.kicad_sch, Moonbeam Midi Keyboard parts Copy 1 - MoonBeam Midi Keyboard_PCB.step]
2025-11-26 Add project updates and board issue fixes
    Added updates regarding project funding and board issues.
2025-12-03 Update README with DAC fix and board status
    Added update regarding DAC issue resolution and current status.
2025-12-03 Update README with known issues
    Added known issues section with details on code and board problems.
2025-12-04 optimized and fixed audio side of code
    [core2.cpp, main.cpp]
